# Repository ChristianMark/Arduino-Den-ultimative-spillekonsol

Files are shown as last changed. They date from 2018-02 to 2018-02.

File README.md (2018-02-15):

# Arduino-Den-ultimative-spillekonsol-
Projektet er udarbejdet i samarbejde mellem Mads, Kaloyan og Christian i 3-ugers perioden 02-01-2018 til 19-01-2018 i kurset “62505 Introduktion til indlejrede systemer”.

Projektoplægget gik ud på, at lave et Arduino projekt. Gruppen besluttede sig for, at lave arduinoen om til en spillekonsol, som kan kommunikere med en RPI. På RPI siden er der databehandling af det modtagne data. Data’en skulle så efterfølgende sorteres og blive tilskrevet i et tekstdokument, der indeholdte en highscore liste.
En tidsplan over projektet blev udarbejdet og den aktuelt “brugt tid” blev løbende tilskrevet tidsplanen, så der løbende blev holdt øje med projektet. Projektet var opdelt i Arduino og RPI. Mads og Christian samarbejde om Arduino delen og Kaloyan stod for databehandling på RPI siden, kommunikation med FTP serveren og TWI kommunikationen mellem RPI og Arduinoen.
Produktet endte med at opfylde de kravspecifikationer som blev opstillet i starten af processen.

Video af hele projektet kan findes her:
https://www.youtube.com/watch?v=zfV5iQ8ZYD8&feature=youtu.be

Python Script på RPI:
https://www.youtube.com/watch?v=egbLoRT4I6c&feature=youtu.be

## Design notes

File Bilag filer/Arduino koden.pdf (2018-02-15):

# Arduino koden

# tic_tac_toe_v1.6.7_Final.ino filen

#include | <Wire.h>

#include | <Adafruit_GFX.h>

#include | <Adafruit_NeoMatrix.h>

#include | <Adafruit_NeoPixel.h>

#include | <LiquidCrystal.h>

const | int | rs = 12, en = 11, d4 = 40, d5 = 41, d6 = 42, d7 = 43;
LiquidCrystal lcd(rs, en, d4, d5, d6, d7);

/////////////PIN CONFIG////////////
#define | PIN 8

#define | PZ_PIN 37

#define | VRX1 A1

#define | VRY1 A2

#define | Switch1 2

#define | VRX2 A3

#define | VRY2 A4

#define | Switch2 3

////////////////////////////////////

////////////TONE MACROS/////////////
#define | ERR_SOUND tone(PZ_PIN, 100, 75);

#define | PRESS_SOUND

#define | WIN_SOUND

#define | DRAW_SOUND

#define | PUT_SOUND tone(PZ_PIN, 2200, 100);

//bitSet(TIMSK5, TOIE5); //sets "TOIEn" in register "TIMSKn" to one. This bit enables timer overflow interrupts.

// Check timer 5 registres
/*
* | Serial.print("TCCR5A:");
* | Serial.println(TCCR5A);
* | Serial.print("TCCR5B:");

* | Serial.println(TCCR5B);
* | Serial.print("TCCR5C:");
* | Serial.println(TCCR5C);
* | Serial.print("OCR5AH:");
* | Serial.println(OCR5AH);
* | Serial.print("OCR5AL:");
* | Serial.println(OCR5AL);
* | Serial.print("OCR5BH:");
* | Serial.println(OCR5BH);
* | Serial.print("OCR5BL:");
* | Serial.println(OCR5BL);
*/

//ISR for timer overflow:
/*
ISR(TIMER5_OVF_vect){
cli();
OCR3A = sigTable[mode][i]; //PWM on pin 5 uses OCR3A as trigger value, set it to defind value

i+=1;
if (i >= SAMPLESIZE - 1){
i = 0;
}//end if
sei();
}//end ISR
*/
/////////////SD CARD////////////////
#include | <SD.h>

#define | SD_PIN 53

//#define DEBUG_writeWinnerToSD //0.53s runtime extra

struct | dataStructure | {
char | points[3];
char | space = ' ';
char | nameSpace[6];
char | newlineC = '\n';
};

////////////COLOR CONFIG////////////

#define PLAYER_1_COLOR matrix.Color(0,0,255)

#define | PLAYER_2_COLOR matrix.Color(0,255,0)

#define | PLAYER_3_COLOR matrix.Color(150,150,150)

#define | CURSOR_1_COLOR matrix.Color(255,0,255)

#define | CURSOR_2_COLOR matrix.Color(255,255,0)

#define | GRID_COLOR matrix.Color(150,150,150)

////////////////////////////////////
#define | MENU_DELAY 250

#define | GAME_DELAY 200

#define | NAME_LENGTH 5

#define | menuSize 2

#define | SCORE_LENGTH 3

#define | LINE_LENGTH (SCORE_LENGTH+NAME_LENGTH+1)

#define | MAX_SCORE 999 // This can only be the number of digits defined

by SCORE_LENGTH
#define | PLAYER1 false

#define | PLAYER2 true

#define | NM

#define | SLAVE_ADDRESS 0x04

#define | RPI_cp 22

//#define DEBUG_sendData
#define DEBUG_timing

///////Macros and variables/////////

#define | CURSOR_POS_IN_AREA gameArea[cursorPos[1]][cursorPos[0]]

char | gameArea[3][3] = {{ 0,0,0 },
{ 0,0,0 },
{ 0,0,0 }};
// 1'taller er player 1 og 0 er tom

boolean turn = PLAYER1; //FALSE eller 0 er player 1
boolean inMenu = false; // False if the game is started and 1 if the statemachine is in the menu
char | cursorPos[2] = {0,0};
char | Move[2] = {0,0};
char | latestPut[2] = {0,0};

char | turns = 0;
unsigned | long | previousMillis = 0; | // will store last time LED was
updated
unsigned | int | interval = 0; | // interval at which to blink
(milliseconds)
volatile | boolean button1_pressed_ISR = false;
volatile | boolean button2_pressed_ISR = false;

boolean button1_detected = false;
boolean button2_detected = false;

enum gamestates {start, going, wonP1, wonP2, draw}; gamestates gamestate = start;

enum menustates {start_menu, running_menu, chnm_menu, game_menu}; menustates menustate = start_menu;
menustates previousMenustate = start_menu;
enum players {p1 = 0, p2 = 1};
players player;
char | player1Name[NAME_LENGTH] = {'M','A','D','S',' '};
char | player2Name[NAME_LENGTH] = {'M','A','R','K',' '};
volatile | boolean sendingDataToRPI = false;
boolean doneSending = false;

///////Functions/////////
extern | void | MoveInArray();
extern | bool | gameAreaFiled(char | xPos, char | yPos);
extern | bool | outOfBounds(char | xPos, char | yPos);
extern | void | animate();
extern | void | drawPiece(char | posX, char | posY, int | color);

//new matrix functions
extern | void | animateNM();
extern | void | drawPieceNM(char | posX, char | posY, int | color);
extern | void | drawGridNM();
extern | void | detectinput(bool | turn);
extern | void | detectput(bool | turn);
extern | boolean find_new_pos();
extern | void | Turndecide();

extern | void | detectGameCondition();
extern | void | p1win();
extern | void | p2win();
extern | void | drawWin();
extern | void | rungame();
extern | void | playerTurnLCD(boolean playerTurn);
extern | void | resetgame();
extern | void | inputName(bool | chnmPlayer);

//SD card func
extern | void | serialPrintArr(char* arr, int | len);
extern | void | writeWinnerToSD(boolean winner);

// Debug func
extern | void | updateD();
extern | void | printNamesSerial();

// Debug macros
//#define DEBUG_detectGameCondition //#define DEBUG_Turndecide //#define DEBUG_MoveInArray //#define DEBUG_animate
//#define DEBUG_detectinput //#define DEBUG_find_new_pos //#define DEBUG_detectput
//#define DEBUG_winner

////////////////////////////////////
// MATRIX DECLARATION:
// Parameter 1 = width of NeoPixel matrix
// Parameter 2 = height of matrix
// Parameter 3 = pin number (most are valid)
// Parameter 4 = matrix layout flags, add together as needed: // NEO_MATRIX_TOP, NEO_MATRIX_BOTTOM, NEO_MATRIX_LEFT, NEO_MATRIX_RIGHT:
// | Position of the FIRST LED in the matrix; pick two, e.g.
// | NEO_MATRIX_TOP + NEO_MATRIX_LEFT for the top-left corner.
// | NEO_MATRIX_ROWS, NEO_MATRIX_COLUMNS: LEDs are arranged in
horizontal
// | rows or in vertical columns, respectively; pick one or the other.
// | NEO_MATRIX_PROGRESSIVE, NEO_MATRIX_ZIGZAG: all rows/columns proceed
// | in the same order, or alternate lines reverse direction; pick
one.
// See example below for these values in action.
// Parameter 5 = pixel type flags, add together as needed:

// NEO_KHZ800 800 KHz bitstream (most NeoPixel products w/WS2812 LEDs)
// NEO_KHZ400 400 KHz (classic 'v1' (not v2) FLORA pixels, WS2811 drivers)
// | NEO_GRB | Pixels are wired for GRB bitstream (most NeoPixel
products)
// | NEO_RGB | Pixels are wired for RGB bitstream (v1 FLORA pixels,
not v2)

// Example for NeoPixel Shield. In this application we'd like to use it // as a 5x8 tall matrix, with the USB port positioned at the top of the // Arduino. When held that way, the first pixel is at the top right, and
// lines are arranged in columns, progressive order. The shield uses // 800 KHz (v2) pixels that expect GRB color data. Adafruit_NeoMatrix matrix = Adafruit_NeoMatrix(8, 8, PIN, NEO_MATRIX_TOP +
NEO_MATRIX_LEFT +
NEO_MATRIX_COLUMNS +
NEO_MATRIX_ZIGZAG,
NEO_GRB | +
NEO_KHZ800);

void setup() {
// put your setup code here, to run once: /////////////////////////////////////
// set up the LCD's number of columns and rows: lcd.begin(16, 2);
// Print a message to the LCD. lcd.print("hello, world!"); ///////////////////////////// Serial.begin(9600);
/////////////////////////////////////////
while | (!Serial) {};
if | (!SD.begin(SD_PIN)) {
Serial.println("Card failed, or not present"); // don't do anything more:
while (1);
}
Serial.println("card initialized."); //////////////////////////////////////////

matrix.begin();

matrix.setBrightness(40);
matrix.fillScreen(0);
matrix.show();

pinMode(VRX1, INPUT);
pinMode(VRY1, INPUT);
pinMode(Switch1, INPUT);
digitalWrite(Switch1, INPUT_PULLUP); attachInterrupt(digitalPinToInterrupt(Switch1),ISR_button1,FALLING);

pinMode(VRX2, INPUT);
pinMode(VRY2, INPUT);
pinMode(Switch2, INPUT);
digitalWrite(Switch2, INPUT_PULLUP); attachInterrupt(digitalPinToInterrupt(Switch2),ISR_button2,FALLING);

Wire.begin(SLAVE_ADDRESS);
Wire.onRequest(sendData);
pinMode(RPI_cp, OUTPUT);

}

void | loop() {
unsigned | long | currentMillis = millis();

switch(menustate){
// {start_menu, running_menu, chnm_menu, game_menu};
case | start_menu:
static | char | toggle_menu = 0;
inMenu = true; // The ISR of button1 now know that the player1 is controlling the menu //turn = 0;
button1_pressed_ISR = 0;
lcd.setCursor(0, 0);
lcd.print("Welcome... | ");
lcd.setCursor(0,1);
lcd.print("Play Tic Tac Toe");
toggle_menu = 0; // The menu is now on "Play Tic Tac Toe"
menustate = running_menu; // Go to running_menu break;

case running_menu:
lcd.setCursor(0, 1);

detectinput(PLAYER1);

//move in menu
if(Move[0] > 0){
toggle_menu++; | //move right in menu
if(toggle_menu == menuSize){toggle_menu=0;}; //wrap around up
} else | if | (Move[0] < 0){
toggle_menu--; | //move left in menu
if(toggle_menu == -1){toggle_menu = menuSize-1;}; //wrap around down

}//end if move left or right

//update menu display if changed
if (Move[0] != 0){
if(toggle_menu == 0){
lcd.print("Play Tic Tac Toe ");
}else | if(toggle_menu == 1){
lcd.print("Change name | ");
}
} // if Moved

//update if the button is pressed if(button1_pressed_ISR){
if(toggle_menu == 0){ // Go to Game menustate = game_menu; // Go to the game_menu next
}else | if | (toggle_menu == 1){ // Go to "Change
name"
menustate = chnm_menu;
}
button1_pressed_ISR = false;
}
if(menustate != running_menu){
inMenu = false; // The Menu StateMachine is now changing to another menu than "start_menu" }
break;

case chnm_menu:

inputName(PLAYER1); // player1 inputName(PLAYER2); // player2 menustate = start_menu;
break;

case game_menu:
//{start, going, wonP1, wonP2, draw}; rungame();

break; // Break for the game state in the menu SM } // Switch/Menu State Machine

//if menustate chagnges, change delay
if (previousMenustate != menustate){
if( menustate == running_menu){
interval = MENU_DELAY ; | //if in menu, apply menu delay
} else | if | (menustate == game_menu){
interval = GAME_DELAY; | //if in game, apply game delay
}
previousMenustate = menustate;
}//end if - previousMenustate

//while this runtime for the program is less than the inteval while(currentMillis - previousMillis <= interval) { currentMillis = millis();
//Serial.println(currnetMillis);

//Here is the place to add sender code
}
currentMillis = millis(); | //update the current time, if we
did not enter while loop
previousMillis = currentMillis; | //update previous time for next
compare

#ifdef DEBUG_timing

Serial.print("Ude, det tog:"); Serial.println(currentMillis - previousMillis); #endif

} // void loop

//////////////////////////////////////////////////// // ISR til knapperne
void | ISR_button1(){
static | unsigned | long | last_interrupt_time = 0;
unsigned | long | interrupt_time = millis();
// If interrupts come faster than 200ms, assume it's a bounce and ignore
if (interrupt_time - last_interrupt_time > 200)
{
if(turn != true || inMenu){ // If it's the player 1's turn or the Menu StateMachine is in Menu.
button1_pressed_ISR = true;
}
}
last_interrupt_time = interrupt_time; }
void | ISR_button2(){
static | unsigned | long | last_interrupt_time = 0;
unsigned | long | interrupt_time = millis();
// If interrupts come faster than 200ms, assume it's a bounce and ignore
if (interrupt_time - last_interrupt_time > 200)
{
if(turn){
button2_pressed_ISR = true; }
}
last_interrupt_time = interrupt_time; }

# LCD_funk.ino filen

/* Change name variables with the analog sticks. Only uses * big letters and space.
* Call with a turn variabel, false for p1, and true for p2 *
*/
void | inputName(bool | chnmPlayer){
char | temp = 0;
char | useOldName_index = 0;

if(chnmPlayer){//Player 2
temp = player2Name[useOldName_index]; }else{//Player 1
temp = player1Name[useOldName_index]; }
bool | button_detect;
bool | old_turn; | //hold old global turn value
old_turn = turn; | //save global turn
turn = chnmPlayer; | //change global turn value

chnmPlayer ? button_detect = button2_pressed_ISR : button_detect = button1_pressed_ISR;

lcd.clear();
if (chnmPlayer){
lcd.print("Player 2 name:"); } else {
lcd.print("Player 1 name:"); }

lcd.setCursor(0,1);
lcd.cursor();
for | (char | i = 0; i < (NAME_LENGTH); ++i){
while | (!button_detect){
lcd.setCursor(i,1);
lcd.write(temp);
detectinput(chnmPlayer); //detect input for player 1
delay(250); | //delay for responsive ness feeling

//increment temp
if (Move[0] > 0){
temp++;
} else if(Move[0] < 0){
temp--;
}//increment temp

//made for looping char choise around
switch | (temp){
case | 91 :
| temp = 32;
| break;
case | 64 :

temp = 32;
break;
case 31 :
temp = 90;
break;
case 33 :
temp = 65;
break;
default :
break;
}//end switch

//poll for button press
chnmPlayer ? button_detect = button2_pressed_ISR : button_detect = button1_pressed_ISR;

}//end while - not pressed

//save char
chnmPlayer ? player2Name[i] = temp : player1Name[i] = temp;

useOldName_index++;
if(chnmPlayer){//Player 2
temp = player2Name[useOldName_index]; }else{//Player 1
temp = player1Name[useOldName_index]; }

//reset press ISR
button1_pressed_ISR = false; button2_pressed_ISR = false; button1_detected = false;
button2_detected = false;
button_detect = false;
}//end for - name
lcd.noCursor();
turn = old_turn; //restore global turn to previous value

}//end inputName

////////////////////////////////////////////// DEBUG FUNCTION //////////////////////////////////
void printNamesSerial(){

for | (char | i = 0; i < NAME_LENGTH; ++i){
Serial.print(player1Name[i]);
}
Serial.println("");
for | (char | i = 0; i < NAME_LENGTH; ++i){
Serial.print(player2Name[i]);
}
}

# RPI_funk.ino filen

void sendOneRecord(){

lcd.setCursor(0 , 1);
lcd.print("Sending data... "); char i = 0;
digitalWrite(RPI_cp, HIGH); while(digitalRead(RPI_cp)){
//Serial.print("This is value of done sending:"); //Serial.println(doneSending);
delay(200);
if (++i > 15){
digitalWrite(RPI_cp, LOW);
| i=0;
}
}
digitalWrite(RPI_cp, LOW); doneSending = false;
}
void | sendData(void) {
static | int | index = 0;
#ifdef | DEBUG_sendData

Serial.print("sendData() was called \n"); #endif

if (turn) {
Wire.write((byte)player1Name[index]); } else {
Wire.write((byte)player2Name[index]); }

index++;

//reset index and done sending if (index >= NAME_LENGTH) { index = 0; doneSending = true; digitalWrite(RPI_cp, LOW);

}

#ifdef DEBUG_sendData

Serial.print("char was sent: ");
if (turn) {
Serial.println(player1Name[index]); } else {
Serial.println(player2Name[index]); }//end if
#endif

}

/*
void receiveData(int byteCount){ while(Wire.available()){
index = (int)Wire.read();
Serial.print("index received: "); Serial.println(index);
}
}
*/

# SD_func.ino filen

void writeWinnerToSD(boolean winner) {
File writeFile; | //for write file
char score[SCORE_LENGTH]; | //to contain score as string
int finalPoints; | //to contain score as int
bool foundName = false; | //used for searching name

if (sendingDataToRPI) {
//if sending data, write date to buffer file if (writeFile = SD.open("buffer.txt", O_RDWR)) { #ifdef DEBUG_writeWinnerToSD
Serial.println("Write file 'buffer.txt' opened"); #endif
} else {
#ifdef DEBUG_writeWinnerToSD

Serial.println("Error, could not open"); #endif
return;
}//end if - open SD
} else { //else open score file

if (writeFile = SD.open("score.txt", O_RDWR)) { #ifdef DEBUG_writeWinnerToSD
Serial.println("Write file 'score.txt' opened"); #endif
} else {

#ifdef DEBUG_writeWinnerToSD Serial.println("Error, could not open"); #endif

return;
}//end if - open SD
}//end if - sendingDataToRPI

//search for player 1 or 2, depending on who wins. if (winner) {
foundName = writeFile.find(player2Name, NAME_LENGTH); } else {
foundName = writeFile.find(player1Name, NAME_LENGTH); }//end if - winner find

#ifdef DEBUG_writeWinnerToSD

Serial.print("The winner is: ");
serialPrintArr(winner ? player2Name : player1Name, NAME_LENGTH); #endif

//if the name is found, 1 is added to players score //if not, a new name has to be added to the list if (foundName) {

#ifdef DEBUG_writeWinnerToSD

Serial.println("player found in highscore"); Serial.print("This is pos after find: "); Serial.println(writeFile.position());
#endif

//jump from end of line to begining of line to read score writeFile.seek(writeFile.position() - LINE_LENGTH);

#ifdef DEBUG_writeWinnerToSD

Serial.print("This is pos after seek: "); Serial.println(writeFile.position());
#endif

//read the SCORE_LENGTH char score into char arr for (char i = 0; i < SCORE_LENGTH; i++) {
score[i] = writeFile.read();
}//end for

#ifdef DEBUG_writeWinnerToSD Serial.print("This is pos after read: "); Serial.println(writeFile.position()); serialPrintArr(score, SCORE_LENGTH); #endif

//jump cursor back to before read writeFile.seek(writeFile.position() - SCORE_LENGTH);

//make the score into an int and add one finalPoints = atoi(score);
finalPoints++;

if(finalPoints > MAX_SCORE){ // The score can only be < MAX_SCORE finalPoints = MAX_SCORE;
Serial.println("The score has been set to MAX_SCORE");
}

//write finalPoints formatted to score again if(SCORE_LENGTH == 3){
sprintf(score, "%03d", finalPoints);
}else{
Serial.println("The 'SCORE_LENGTH' MACRO has been changed from 3, go change code in SD_FUNC");
}

#ifdef DEBUG_writeWinnerToSD Serial.println(finalPoints); Serial.print("New score: "); serialPrintArr(score, SCORE_LENGTH); #endif

//write the score to the place in file writeFile.write(score);

} else {
//the playername was not found in highscore list

#ifdef DEBUG_writeWinnerToSD Serial.println("player not found in highscore"); Serial.print("This is pos after find:"); Serial.println(writeFile.position());

#endif

//position is now at the end of the file, since we could not find the player

//now write the first point for player for(char i = 0; i < SCORE_LENGTH - 1; i++){ writeFile.write("0");
}
writeFile.write("1 ");

//writeFile.write("001 ");

//now write playerName to file
if (winner) {
for (char i = 0; i < NAME_LENGTH; i++) { writeFile.write(player2Name[i]);
}
} else {
for (char i = 0; i < NAME_LENGTH; i++) { writeFile.write(player1Name[i]);
}
}//end if - winner find

writeFile.write("\n");
#ifdef DEBUG_writeWinnerToSD Serial.print("This is pos after write:"); Serial.println(writeFile.position());

#endif

}//if else - foundname

//close the file as the file is only to be used in function writeFile.close();
}//end function - writeWinnerToSD

//////////////////////////////// DEBUG FUNCTION //////////////////////////////////

void serialPrintArr(char* arr, int len) {
for (char i = 0; i < len; i++) { Serial.print(arr[i]);
Serial.print(", ");
}
Serial.println("");
}

# Tic_tac_toe_funk.ino filen

void rungame(){
switch(gamestate){
case start:
resetgame(); // Restart the game variabels and print gamestate = going;
break;
case going:
//Print to the LCD
playerTurnLCD(turn);

//Get input from player
detectinput(turn);

//Move cursor in array
MoveInArray();

//Check for button pressed detectput(turn);

//Detect if the game has been won or if its a draw detectGameCondition();

// Decide if the turn should change
Turndecide();

// Send out the array to the LED Matrix #ifndef NM
animate();
#else

animateNM();
#endif

//delay(100);
break;
case wonP1...wonP2:
delay(1000);
matrix.fillScreen(0);
matrix.show();

// When someone has won, the SM has already shifted the turn to the other player with the Turndecide() func, so we need to invert the turn.
playerTurnLCD(!turn);

if(gamestate == wonP1){
boolean toggle = true;

for(int j=0;j<3;j++){
if(toggle){
for(int | i=0;i<3;i++){
#ifndef | NM

drawPiece(i,j,PLAYER_1_COLOR); #else
drawPieceNM(i,j,PLAYER_1_COLOR); #endif
matrix.show();
delay(300);
}
toggle = !toggle;
}else{
for(int i=2;i>-1;i--){
#ifndef NM

drawPiece(i,j,PLAYER_1_COLOR); #else

drawPieceNM(i,j,PLAYER_1_COLOR); #endif
matrix.show();
delay(300);
}
toggle = !toggle;
}
}
}else if(gamestate == wonP2) { boolean toggle = true;

for(int j=0;j<3;j++){
if(toggle){
for(int | i=0;i<3;i++){
#ifndef | NM

drawPiece(i,j,PLAYER_2_COLOR); #else
drawPieceNM(i,j,PLAYER_2_COLOR); #endif
matrix.show();
delay(300);
}
toggle = !toggle;
}else{
for(int i=2;i>-1;i--){
#ifndef NM

drawPiece(i,j,PLAYER_2_COLOR); #else
drawPieceNM(i,j,PLAYER_2_COLOR); #endif
matrix.show();
delay(300);
}
toggle = !toggle;
}
}
}
// When someone has won, the SM has already shifted the turn to the other player with the Turndecide() func, so we need to invert the turn to get the winner.
writeWinnerToSD(!turn);
//send til RPI
sendOneRecord();
gamestate = start;
menustate = start_menu;

break;

//The game has ended in a draw case draw:
delay(1000);
matrix.fillScreen(0);
matrix.show();
lcd.setCursor(0,1);
lcd.print("It's a draw!");

boolean toggle = true;

for(int j=0;j<3;j++){
if(toggle){
for(int | i=0;i<3;i++){
#ifndef | NM

drawPiece(i,j,PLAYER_3_COLOR); #else
drawPieceNM(i,j,PLAYER_3_COLOR); #endif
matrix.show();
delay(300);
}
toggle = !toggle;
}else{
for(int i=2;i>-1;i--){
#ifndef NM

drawPiece(i,j,PLAYER_3_COLOR); #else
drawPieceNM(i,j,PLAYER_3_COLOR); #endif
matrix.show();
delay(300);
}
toggle = !toggle;
}
}
gamestate = start;
menustate = start_menu;
break;
} // Switch/ Game State Machine }//end run-game

/*
* Decides whos turn it is

*/
void Turndecide(){
if(turn){// Player 2
if(button2_detected ){
#ifdef DEBUG_Turndecide

Serial.println("Its now player 1's turn"); #endif
turn = PLAYER1;
button2_detected = false;
}
}else{// Player 1
if(button1_detected ){
#ifdef DEBUG_Turndecide

Serial.println("Its now player 2's turn"); #endif
turn = PLAYER2;
button1_detected = false;
}
}
}

/*
* Function takes the move, sees if it is possible and if so, moves the cursor
*/
void | MoveInArray(){
char | newCursorPos[2] = {0,0}; // for checking
newCursorPos[0] = cursorPos[0] + Move[0]; newCursorPos[1] = cursorPos[1] + Move[1];
if | (outOfBounds(newCursorPos[0],newCursorPos[1])){
#ifdef | DEBUG_MoveInArray

Serial.println("First bound check failed"); #endif

return;
}

cursorPos[0] = newCursorPos[0]; cursorPos[1] = newCursorPos[1]; return;
}

/*
* returns true if the input position is out of the array

*/
bool | outOfBounds(char | xPos, char | yPos){
if | (xPos > 2 || xPos < 0 || yPos > 2 || yPos < 0){
return | true;
} else | {
return | false;
}
}

/*
* returns true if the input position is filled already */
bool | gameAreaFiled(char | xPos, char | yPos){
if | ((gameArea[yPos] [xPos]) != 0){
return | true;
} else | {
return | false;
}
}

/* NEW LED MATRIX FUNC
* Runs the animation funcktion, animates the board and cursor on the new led matrix
*/
void animateNM(){
matrix.fillScreen(0);

drawGridNM(); //draw grid

//run through game area and print it in players colors
for(size_t | i = 0; i < 3; i++){
for | (size_t | j = 0; j < 3; j++){
switch | (gameArea[j][i]){
case | 1:
#ifdef | DEBUG_animate

Serial.println("Player 1's tile is being printed"); #endif
drawPieceNM(i, j,PLAYER_1_COLOR);
break;
case | 2:
#ifdef | DEBUG_animate

Serial.println("Player 2's tile is being printed"); #endif
drawPieceNM(i, j,PLAYER_2_COLOR);
break;

default:
break;
}//end switch
}//end for
}//end for

//animate cursor position
if(gamestate == going){
#ifdef DEBUG_animate

Serial.println("The Cursor is being printed");
#endif

drawPieceNM(cursorPos[0], cursorPos[1], (turn ? CURSOR_2_COLOR : CURSOR_1_COLOR));
}
matrix.show();
}

/* NEW LED MATRIX FUNC
* Function draws a piece on the NEW LED matrix from a gameArea coordinate
*/
void | drawPieceNM(char | posX, char | posY, int | color){
matrix.drawPixel((posX * 3),(posY * 3),color); matrix.drawPixel((posX * 3)+1,(posY * 3),color); matrix.drawPixel((posX * 3),(posY * 3)+1,color); matrix.drawPixel((posX * 3)+1,(posY * 3)+1,color); }
extern | void | drawGridNM(){
for | (char | y = 2; y < 6; y += 3){
for | (char | x = 0; x < 8; x++){
matrix.drawPixel(x, y, GRID_COLOR); }
}
for | (char | x = 2; x < 6; x += 3){
for | (char | y = 0; y < 8; y++){
matrix.drawPixel(x, y, GRID_COLOR); }
}

}
/*Runs the animation funcktion, animates the board and cursor */
void animate(){
matrix.fillScreen(0);
//run through game area and print it in players colors

for(size_t | i = 0; i < 3; i++){
for | (size_t | j = 0; j < 3; j++){
switch | (gameArea[j][i]){
case | 1:
#ifdef | DEBUG_animate

Serial.println("Player 1's tile is being printed"); #endif
drawPiece(i, j,PLAYER_1_COLOR);
break;
case | 2:
#ifdef | DEBUG_animate

Serial.println("Player 2's tile is being printed"); #endif
drawPiece(i, j,PLAYER_2_COLOR);
break;
default:
break;
}//end switch
}//end for
}//end for

//animate cursor position
if(gamestate == going){
#ifdef DEBUG_animate

Serial.println("The Cursor is being printed");
#endif

drawPiece(cursorPos[0], cursorPos[1], (turn ? CURSOR_2_COLOR : CURSOR_1_COLOR));
}
matrix.show();
}

/*Function draws a piece on the LED matrix from a gameArea coordinate */
void | drawPiece(char | posX, char | posY, int | color){
matrix.drawPixel((posX * 2),(posY*2),color); matrix.drawPixel((posX * 2)+1,(posY*2),color); matrix.drawPixel((posX * 2),(posY*2)+1,color); matrix.drawPixel((posX * 2)+1,(posY*2)+1,color);
}

/* DetectInput() recieves a boolean "turn" which indicades who's turn it is. The func will change the Move[] array and return */
void | detectinput(bool | turn){
int | x,y = 0;

if(turn){ // Chooses which analog stick that needs to be read from // Player 2
x = analogRead(VRX2); // Read from the x-axis
y = analogRead(VRY2); // Read from the y-axis

#ifdef DEBUG_detectinput

Serial.print("VRX2:");
Serial.print(x);
Serial.print("\tVRY2:");
Serial.println(y);
#endif

}else{
// Player 1
x = analogRead(VRX1); // Read from the x-axis y = analogRead(VRY1); // Read from the y-axis

#ifdef DEBUG_detectinput

Serial.print("VRX1:");
Serial.print(x);
Serial.print("\tVRY1:");
Serial.println(y);
#endif

}

//Decides which direction the analog stick is facing on the x-axis if( x > 800){
#ifdef DEBUG_detectinput

Serial.println("The analog stick is facing left"); #endif

Move[0] = 1;
}else if(x < 300){
#ifdef DEBUG_detectinput

Serial.println("The analog stick is facing right"); #endif
Move[0] = -1;
}else{
Move[0] = 0;
}

//Decides which direction the analog stick is facing on the y-axis if( y > 800){
#ifdef DEBUG_detectinput

Serial.println("The analog stick is facing up");

#endif

Move[1] = 1;
}else if(y < 300){
#ifdef DEBUG_detectinput

Serial.println("The analog stick is facing down"); #endif
Move[1] = -1;

}else{
Move[1] = 0;
}
return;
}

/*The function finds the first "legal" position in the gameArea to place the cursor*/
boolean find_new_pos(){
for(char | i = 0;i<3;i++){
for(char | j = 0;j<3;j++){
if(gameAreaFiled(j, i) == 0){ cursorPos[0] = j;
cursorPos[1] = i;
#ifdef DEBUG_find_new_pos Serial.println("A new position has been found");

#endif

return 1;
}
}
}
return 0; // No new position available
}

/*The function detects a button press, inserts a '1' or '2' *on the position of the cursor in the gameArea Array and *finds a new legal position for the cursor */
void | detectput(bool | turn){

if(turn){
if(button2_pressed_ISR){
| #ifdef | DEBUG_detectput Serial.println("Button 2 has been pressed");
| #endif

button2_pressed_ISR = false; // These var must be reset, because they can be toggled anytime by the ISR button1_pressed_ISR = false;

if (!gameAreaFiled(cursorPos[0],cursorPos[1] )){ PUT_SOUND
//Serial.println("second filld check failed"); button2_detected = true; // This var must be set, because we need to know that the game has registered a button press turns++; // Increment the amount of turns CURSOR_POS_IN_AREA = 2; // Indsætter player 2's træk på banen
//Saves the cursorposition where a 1 or 2 has been placed. This is used in the func "detectGameCondition()" latestPut[0] = cursorPos[0];
latestPut[1] = cursorPos[1];
#ifdef | DEBUG_detectput | // Prints out the array on

the Serial monitor
updateD();
#endif

find_new_pos(); //Find a new "legal" position for the cursor
return;
} else {
ERR_SOUND
}

} // end if
}else{
if(button1_pressed_ISR){
#ifdef DEBUG_detectput

Serial.println("Button 1 has been pressed"); #endif
button1_pressed_ISR = false;// These var must be reset, because they can be toggled anytime by the ISR button2_pressed_ISR = false;

if (!gameAreaFiled(cursorPos[0],cursorPos[1] )){ PUT_SOUND
button1_detected = true; //This var must be set, because we need to know that the game has registered a button press turns++; // Increment the amount of turns CURSOR_POS_IN_AREA = 1; // Indsætter player 1's træk på banen
//Saves the cursorposition where a 1 or 2 has been placed. This is used in the func "detectGameCondition()" latestPut[0] = cursorPos[0]; latestPut[1] = cursorPos[1]; #ifdef DEBUG_detectput
updateD();
#endif

find_new_pos(); //Find a new "legal" position for the cursor
} else {
ERR_SOUND
}// end if gameAreaField() } // end if
} // end else
} // end func

/*
* Make life great again
* Detect the winner/draw and change game state. */
void | detectGameCondition(){
char | xCheck = 0;
char | yCheck = 0;
if | (button1_detected || button2_detected){
#ifdef | DEBUG_detectGameCondition

Serial.println("Check win begun"); #endif
/////////////////// Check column win /////////////////// //first make x coordinate to check
xCheck = latestPut[0] + 1;
if (xCheck > 2){
xCheck = 0;
}//end if - xCheck overflow

#ifdef DEBUG_detectGameCondition

Serial.print("First X coordinate generatred:\t"); Serial.println((int)xCheck);
#endif

if (gameArea[latestPut[1]][xCheck] == gameArea[latestPut[1]][latestPut[0]]){

#ifdef DEBUG_detectGameCondition

Serial.println("First test coordnate matches latest put"); #endif

//second make x coordinate to check xCheck++;
if (xCheck > 2){
xCheck = 0;
}//end if - xCheck overflow

#ifdef DEBUG_detectGameCondition

Serial.print("Second X coordinate generatred:\t"); Serial.println((int)xCheck);
#endif

if (gameArea[latestPut[1]][xCheck] == gameArea[latestPut[1]][latestPut[0]]){

#ifdef DEBUG_detectGameCondition Serial.println("Someone won");

#endif

if (gameArea[latestPut[1]][latestPut[0]] == 1){ p1win();
return;
} else | if | (gameArea[latestPut[1]][latestPut[0]] == 2){
p2win();
return;
}//end if - change gamestate
}//end if - second check "win check"
}//end if - first check

/////////////////// Check row win /////////////////// //first make y coordinate to check
yCheck = latestPut[1] + 1;
if (yCheck > 2){
yCheck = 0;
}//end if - yCheck overflow

#ifdef DEBUG_detectGameCondition

Serial.print("First Y coordinate generatred:\t"); Serial.println((int)yCheck);
#endif

if (gameArea[yCheck][latestPut[0]] == gameArea[latestPut[1]][latestPut[0]]){

#ifdef DEBUG_detectGameCondition

Serial.println("First test coordnate matches latest put"); #endif

//second make x coordinate to check
yCheck++;
if (yCheck > 2){
yCheck = 0;
}//end if - yCheck overflow

#ifdef DEBUG_detectGameCondition

Serial.print("Second Y coordinate generatred:\t"); Serial.println((int)yCheck);
#endif

if (gameArea[yCheck][latestPut[0]] == gameArea[latestPut[1]][latestPut[0]]){

#ifdef DEBUG_detectGameCondition Serial.println("Someone won");

#endif

if (gameArea[latestPut[1]][latestPut[0]] == 1){ p1win();
return;
} else | if | (gameArea[latestPut[1]][latestPut[0]] == 2){
p2win();
return;
}//end if - change gamestate
}//end if - second check "win check"
}//end if - first check

/////////////////// Check diagonal win ///////////////////
if ((latestPut[0] == latestPut[1]) || ((latestPut[0] - latestPut[1]) % 2 == 0)){
//check if latest put is inside diagonals
//might be more work to check if i should check, please reasearch that! -Mads

if ((gameArea[0][0] == gameArea[1][1] && gameArea[1][1] == gameArea[2][2]) || (gameArea[0][2] == gameArea[2][0] && gameArea[1][1] == gameArea[2][0])){

#ifdef DEBUG_detectGameCondition Serial.println("Diagonal win detected");

#endif

//winner clearly has the middel if (gameArea[1][1] == 1){ p1win();
return;
} else | if | (gameArea[1][1] == 2){
p2win();
return;
}//end if - change gamestate }//end if - diagonal win
}//end if - last put on diagonal if(turns == 9){
drawWin();
return;
}
}//end if buttons detected }//end function detect win state

/* Printning out the Array on the Serial monitor (DEBUG)*/
void | updateD(){
for(size_t | i = 0; i < 3; i++){
for | (size_t | j = 0; j < 3; j++){
Serial.print((int)gameArea[i][j]); }
Serial.println();
}Serial.println();

}//end updateD

void p1win(){
gamestate = wonP1;
#ifdef DEBUG_winner

Serial.println("Player 1 won"); #endif

}//end p1win

void p2win(){
gamestate = wonP2;
#ifdef DEBUG_winner

Serial.println("Player 2 won"); #endif

}//end p2win

void drawWin(){
gamestate = draw;
#ifdef DEBUG_winner

Serial.println("draw detected, 9 moves used"); #endif

}//end drawWin

void playerTurnLCD(boolean playerTurn){

if(playerTurn){ // Player 2 if(gamestate == going){
lcd.setCursor(0,1);
for(char i = 0;i<NAME_LENGTH;i++){ lcd.print(player2Name[i]);
}
}else if(gamestate == wonP2){ lcd.setCursor(0,1);
for(char i = 0;i<NAME_LENGTH;i++){ lcd.print(player2Name[i]);
}
lcd.print(" wins");
}
}else{ // Player 1
if(gamestate == going){ // Prints the player name for whome has the turn
lcd.setCursor(0,1);
for(char i = 0; i < NAME_LENGTH;i++){ lcd.print(player1Name[i]);
}
}else if(gamestate == wonP1){ // Prints the player name for who won.
lcd.setCursor(0,1);
for(char i = 0;i<NAME_LENGTH;i++){ lcd.print(player1Name[i]);
}
lcd.print(" wins");
}
}
lcd.noCursor(); // Remove the cursor }

void resetgame(){

button1_pressed_ISR = false; button2_pressed_ISR = false; button1_detected = false;
button2_detected = false;
cursorPos[0] = 0;
cursorPos[1] = 0;
latestPut[0]= 0;
latestPut[1]= 0;
turns = 0;

//Write to LCD
lcd.clear();
lcd.setCursor(0, 0);
lcd.print("Tic Tac Toe");
//Reset the gameArea and the LED Maxtrix
for(int | i = 0;i<3;i++){
for(int | j = 0;j<3;j++){
gameArea[i][j] = 0;
}
}
matrix.fillScreen(0);
matrix.show();
}

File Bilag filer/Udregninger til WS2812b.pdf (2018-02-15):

(2)

(1)

(11)

(6)

(4)

(8)

(10)

(9)

(13)

(5)

(7)

(12)

(3)

### 1.25 µs$24 bits # tiden det tager at sende 24 bits 30.00 µs bits

30 µs$64 LEDSC50 µs $LEDS #tiden det tager at opdatere hele displayet C et reset signal på 50 µs 1970 µs LEDS
µs to Seonds = 10K6

Her udregner vi ved, hvilken frekvens vi kan opdatere hele displayet ved:
evalf 1 1970 $10K6
$Hz

507.6142132 Hz
Biblioteket der bruges kan opsættes til at sende ved forskellige hastigheder.
Her udregner vi, at de kan sende ved de anførte 800 KHz, da det tager 1.25µs at sende et bit evalf 1 1.25 $10K6
$Hz

800000.0000 Hz

Strømforbrugsudregning:
En side siger at WS2812 max kan trække 0.3 W per RGB LED: https://goo.gl/9KNhDp "Aliexpress. com WS2812B 8x8 LED display"
W = V$I
W = I V

### 64 RGB LED trækker = 64$0.3 W 64 RGB LED trækker = 19.2 W 19.2 W = 5$I 19.2 W = 5 I

I =

19.2
5

$A
I = 3.840000000 A
En anden side siger, at de trækker 50 mA per RGB LED max: https://www.pololu.com/product/2547 evalf 50 m$A$64
| 1000$m
3.200000000 A

### 3.2 A$5 V = 16 W 16.0 A V = 16 W 64 RGB LED trækker = 16$W 64 RGB LED trækker = 16 W

Vi har sat brightness til 40 ud af 255, så det tænkes at det kan medregnes i det tiltænkt strømforbrug 40
255 $3.2 A
0.5019607843 A
40
255 $3.84 A
0.6023529412 A

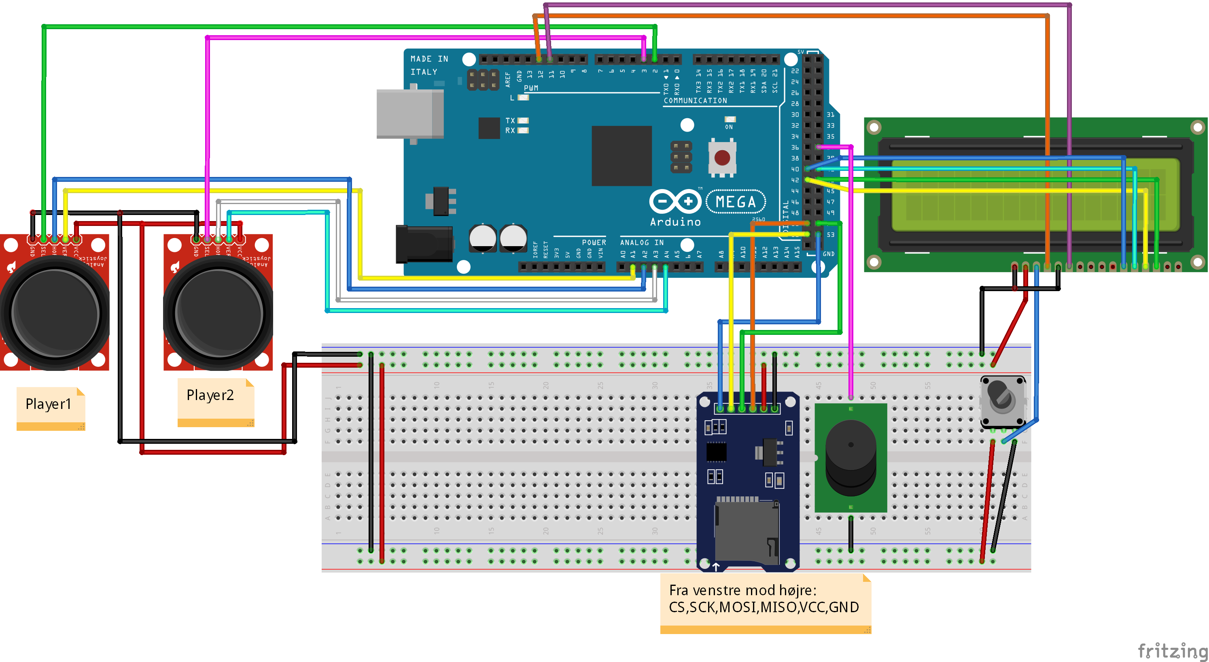
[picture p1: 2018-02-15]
Bilag filer/Arduino kredsløbsdiagram_bb_uden_RPI.png

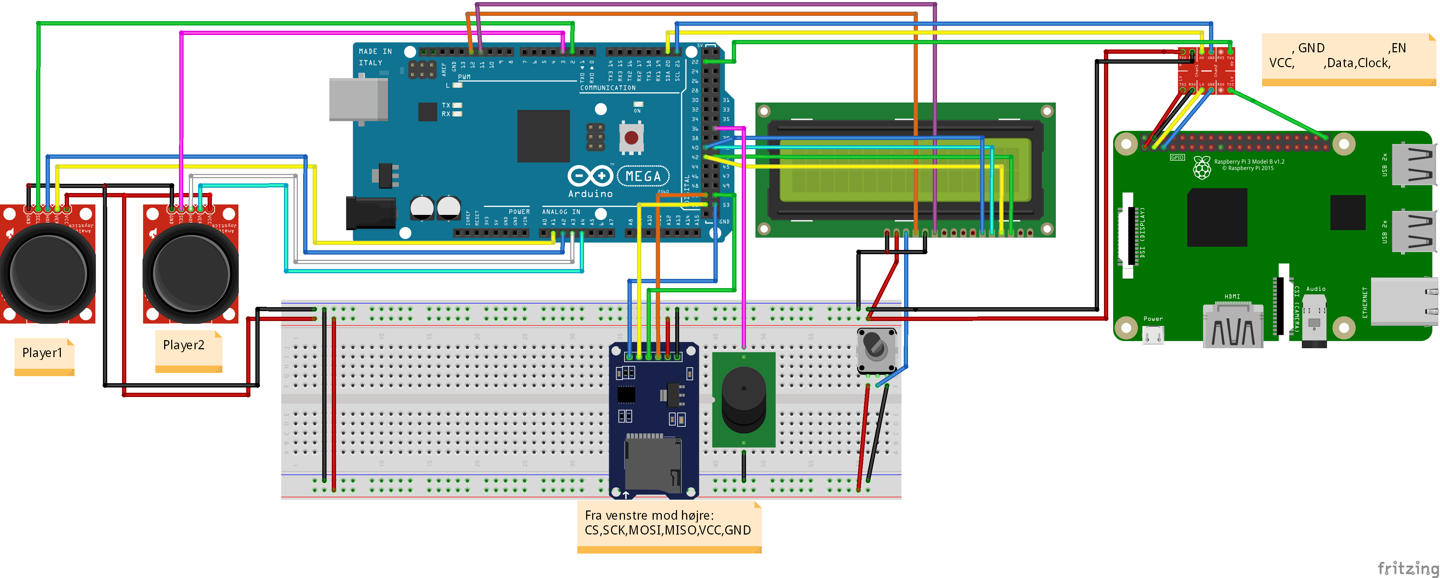
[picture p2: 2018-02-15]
Bilag filer/Arduino kredsløbsdiagram med RPI_bb.png

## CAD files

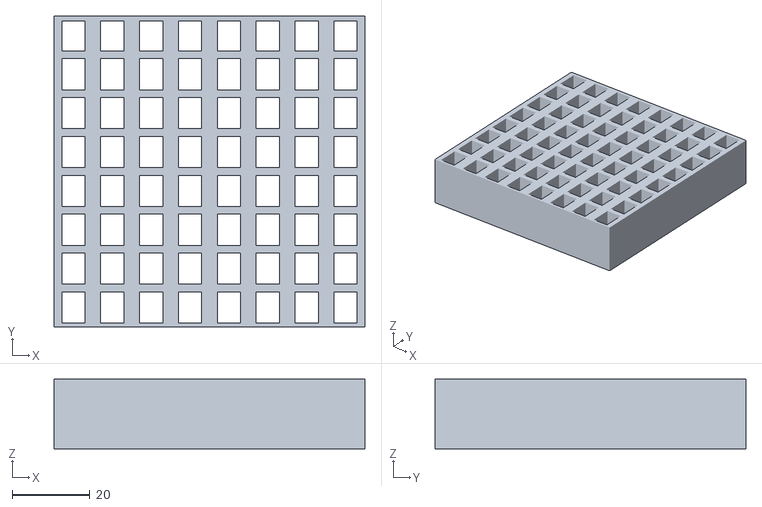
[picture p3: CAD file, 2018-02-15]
3D print filer/Led_matrix.STL
80.0 x 80.0 x 18.0

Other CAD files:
3D print filer/led_matrix2.dwg
3D print filer/LED_MATRIX_ARRAY_print_v0.5.skp
3D print filer/led_matrix.dwg

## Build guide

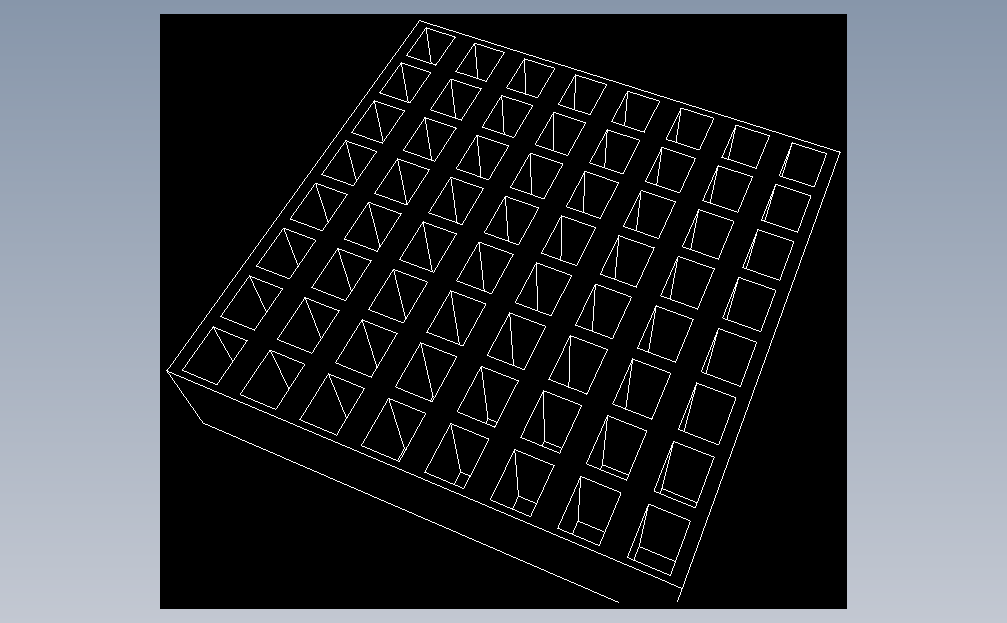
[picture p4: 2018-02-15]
3D print filer/led_matrix.png

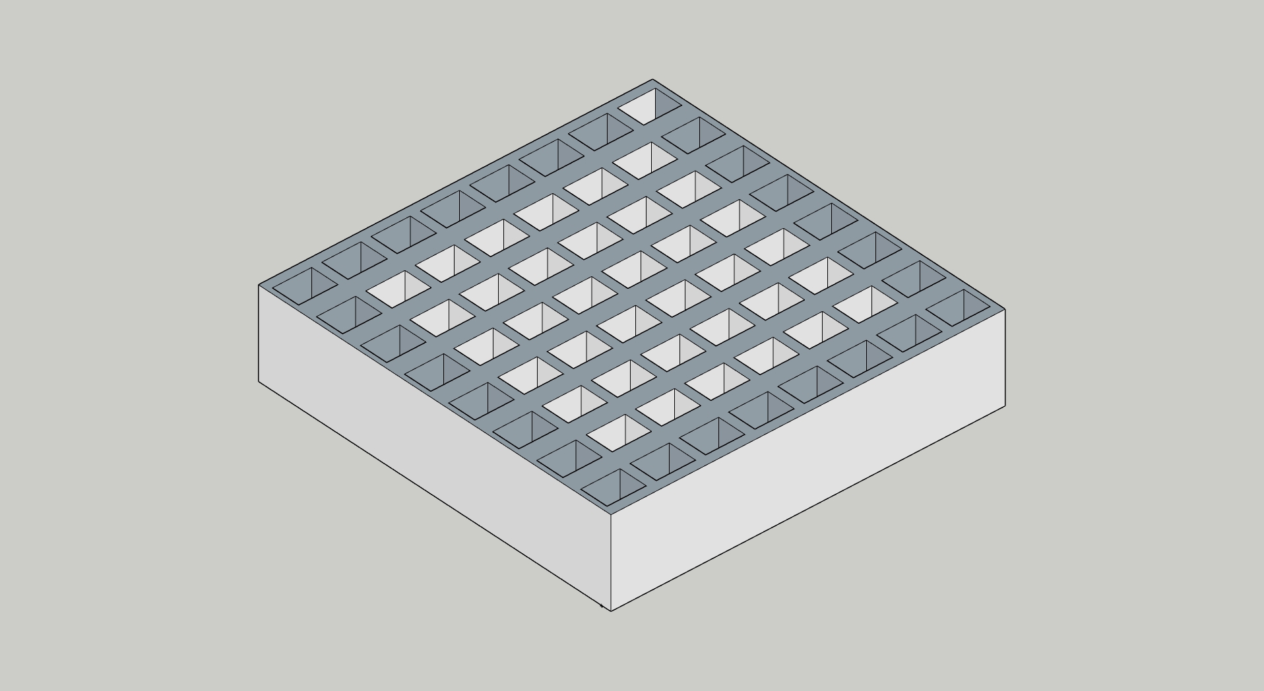
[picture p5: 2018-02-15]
3D print filer/LED_MATRIX_ARRAY_print_v0.jpg

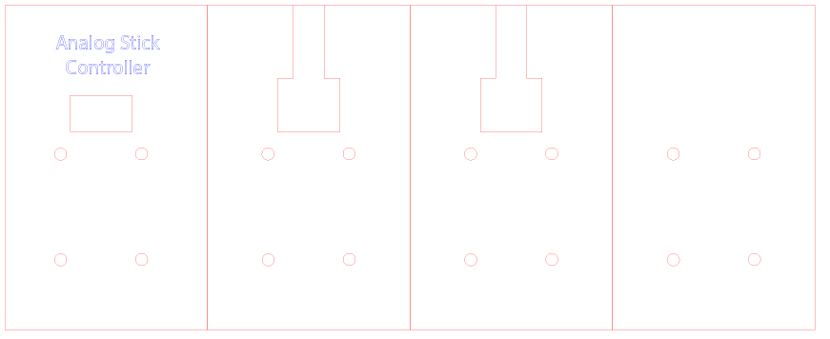
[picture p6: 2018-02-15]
3D print filer/Controllerne.PNG

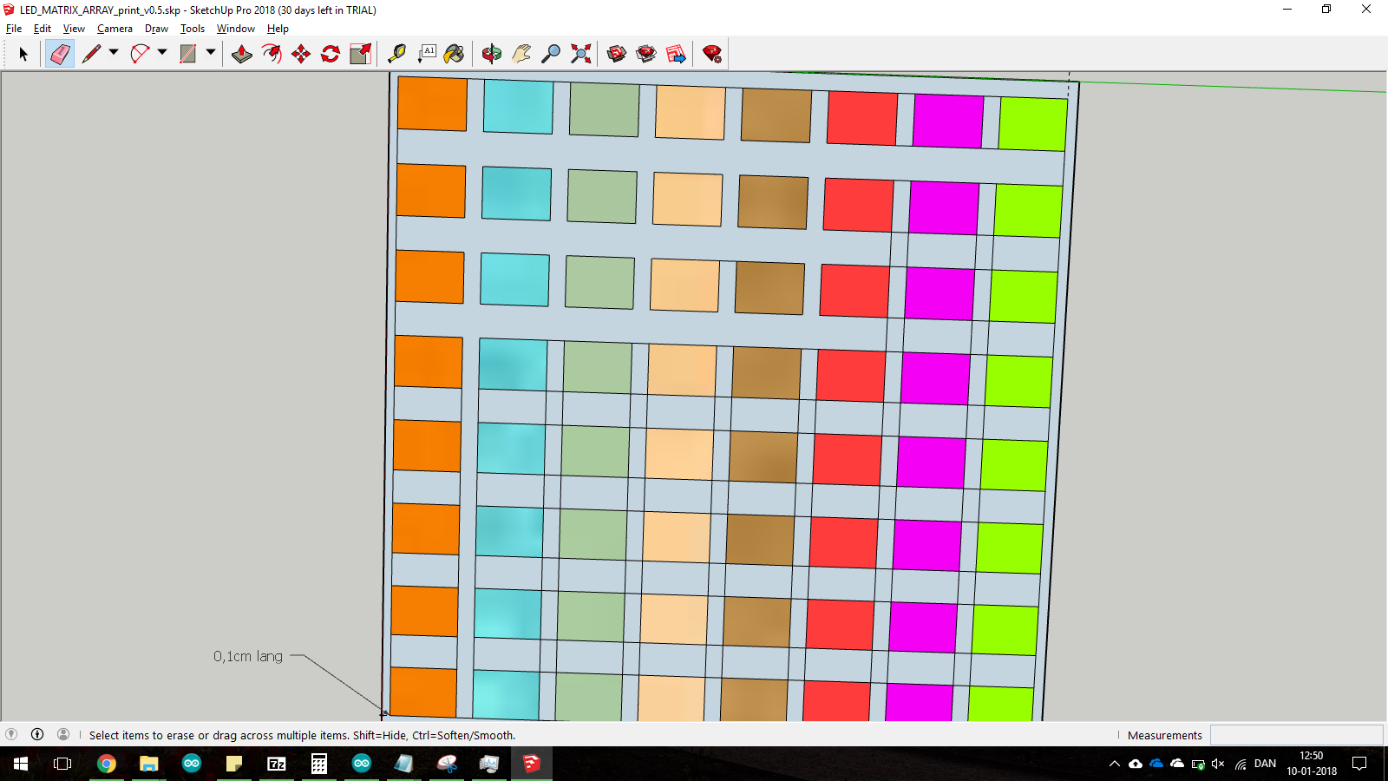
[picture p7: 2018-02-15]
3D print filer/3d print design.png

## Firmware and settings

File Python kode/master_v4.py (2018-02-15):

import smbus
import time
import RPi.GPIO as GPIO

from functionStorage import addOneScore
from functionStorage import uploadFileToWeb

GPIO.setmode(GPIO.BCM)    #use BCM
GPIO.setup(21,GPIO.IN)    #use pin 21 as signal from slave to request data
bus = smbus.SMBus(1)      #activate the two way interface bus
slaveAddress = 0x04       #the address of the slave

def writeByte(value):
    bus.write_byte(slaveAddress, value)    
    return -1

def readByte():
    value = bus.read_byte(slaveAddress)
    return value

name = ""

while True:  
    while not GPIO.input(21):               #check if slave signals 
        time.sleep(0.1)                     #delay
        print("wait for slave to call")
    print("slave to called")    
    
    for n in range(0,5):                    #request name of 5 chars
        name = name + str( chr(readByte()) )
        time.sleep(0.1)                     #enable delay during debug on arduino
        
    print("Recieved name from Arduino: {}".format(name))
    addOneScore(name, "scores_v2.txt")
    uploadFileToWeb("scores_v2.txt",'files.000webhost.com','marksauer','V1IpWadgMOD',"public_html")
    time.sleep(2)
    name = ""    

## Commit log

2018-02-15 Arduino koden
2018-02-15 Alle bilag der blev afleveret med projektet
    Indeholder bl.a kredsløbsdiagramer, link til videoere, udregninger og arduino kode.
    [Arduino kredsløbsdiagram med Power supply.fzz, Arduino kredsløbsdiagram med RPI.fzz, Arduino kredsløbsdiagram.fzz]
2018-02-15 Python og test arduino kode
2018-02-15 Samling af 3D print og laser skæringsfiler
    Der blev 3D printet to controller der kunne holde på de to analog joysticks. Derudover
    [LED_MATRIX_ARRAY_print_v0.5.skp, Led_matrix.STL, led_matrix.dwg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]
